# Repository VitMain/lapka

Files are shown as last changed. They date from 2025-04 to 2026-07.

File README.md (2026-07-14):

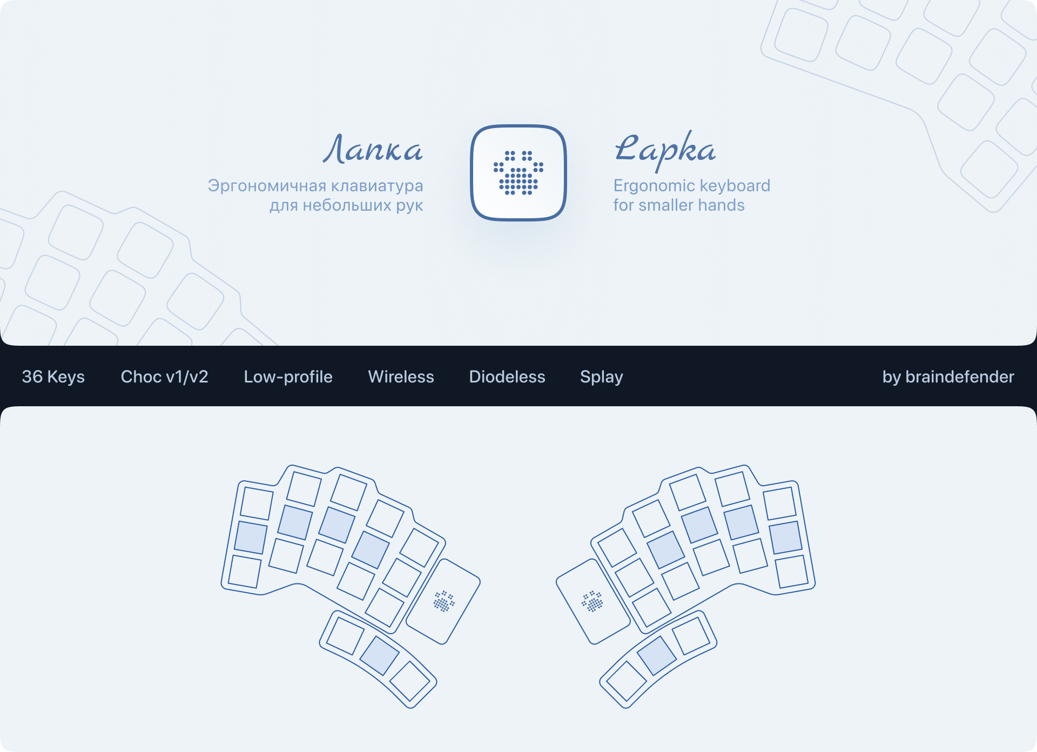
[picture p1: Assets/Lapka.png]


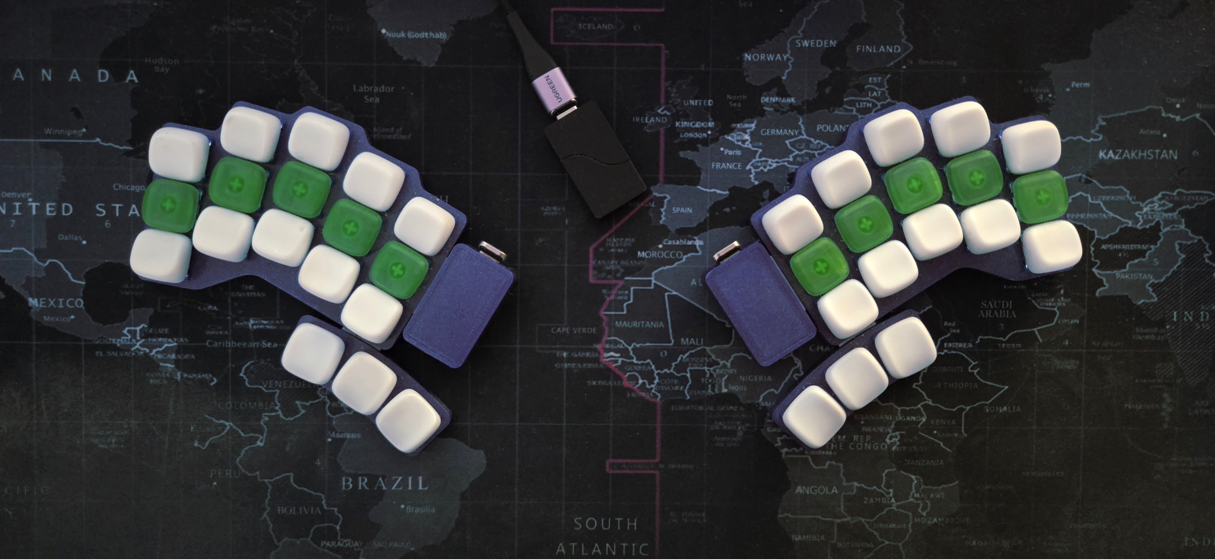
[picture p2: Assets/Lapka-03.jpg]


# Лапка

Беспроводная эргономичная сплит-клавиатура для тех, у кого лапки (:

**Особенности:**
- 36 клавиш, совместима с Choc v2 свитчами
- Direct-pin подключение — при сборке не требуются диоды
- Низкопрофильный корпус (свитчи практически касаются стола)

**Структура репозитория:**

| Директория | Описание |
| ---: | :--- |
| 3MF | Проект OrcaSlicer (для примера параметров печати) |
| Assets | Изображения и фото |
| Fusion | Проект Autodesk Fusion 360 |
| Gerbers | Gerber-файлы для производства плат |
| Guide | Описание [процесса сборки](./Guide/build-guide-ru.md) |
| KiCad | Проект KiCad (схема, плата, компоненты) |
| STL | 3D-модели частей корпуса |

Ссылки на актуальные прошивки:
- [ZMK](https://github.com/braindefender/lapka-zmk-config)
- [RMK](https://github.com/braindefender/lapka-rmk-config)

## RMK

Следуйте инструкциям в README.md репозитория с RMK прошивкой.

## ZMK

Используйте вариант подключения direct-pin, описанный в `lapka_wellum36_left.overlay` и `lapka_wellum36_right.overlay`.

Откройте GitHub Actions и найдите последний успешно собранный билд ветки `lapka-36`.
В нём будет артефакт сборки `firmware.zip`, который содержит все нужные для прошивки файлы.

Тестовая прошивка расположена в ветке `lapka-36-test`. В ней всего один слой и клавиши на тамб-кластере заменены на F1-F6. Это позволит увидеть нажатия клавиш на [key-test.ru](https://key-test.ru).

## История изменений

### v2.2
- Добавлена ссылка на репозиторий прошивки RMK

### v2.1
- Изменена ссылка на репозиторий прошивки ZMK

### v2
- Добавлена поддержка Choc v1
- Изменена разметка пинов
- Обновлена шелкография, логотип перенесён на Cu слой
- Добавлен проект Fusion 360

### v1
- Первый релиз. Только для Choc v2

# Lapka

Wireless ergonomic split keyboard for those who have paws (:

**Peculiarities:**
- 36 keys, Choc v2 compatible
- Direct-pin connection — no diodes needed required
- Low-profile case (switches almost touch the table)

**Repository structure:**

| Directory | Description |
| ---: | :--- |
| 3MF | OrcaSlicer project files (printing parameters example) |
| Assets | Images and photos |
| Fusion | Autodesk Fusion 360 project |
| Gerbers | Gerber-files for PCB production |
| Guide | [Build guide](./Guide/build-guide-en.md) |
| KiCad | KiCad project (schematics, PCB design, components) |
| STL | 3D-models of case parts |

Links to the current firmwares:
- [ZMK](https://github.com/braindefender/lapka-zmk-config).
- [RMK](https://github.com/braindefender/lapka-rmk-config).

## RMK

Follow the instructions in the README.md file of the RMK firmware repository.

## ZMK

Use direct pin layout, described in `lapka_wellum36_left.overlay` and `lapka_wellum36_right.overlay`.

Open GitHub Actions and find latest successful build of branch `lapka-36`.
In that build you'll find artifact `firmware.zip`, which contain all the neccessary firmware files.

Test firmware is located in branch `lapka-36-test`. There are single layer with F1-F6 keys on the thumb-cluster. That will help to see keypresses on the [key-test.ru](https://key-test.ru).

## Changelog

### v2.2
- Added link to RMK Firmware repo

### v2.1
- Changed link to ZMK Firmware repo

### v2
- Added support for Choc v1
- Changed pin layout
- Updated silk-screen, moved logo to Cu layer
- Added Fusion 360 project

### v1
- Initial release. Only for Choc v2

## Фото / Photos

### Original

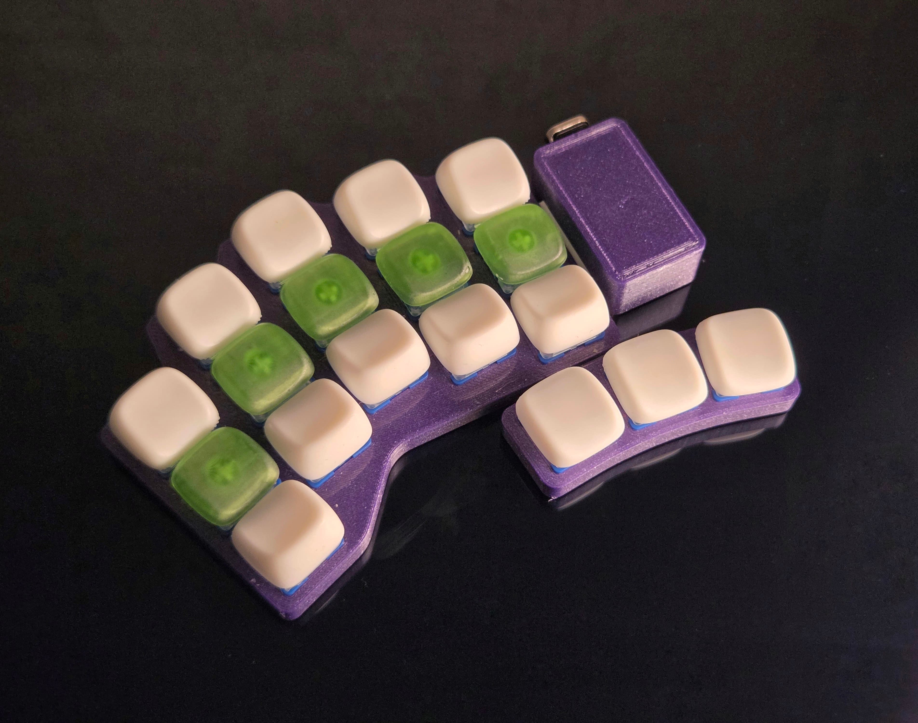
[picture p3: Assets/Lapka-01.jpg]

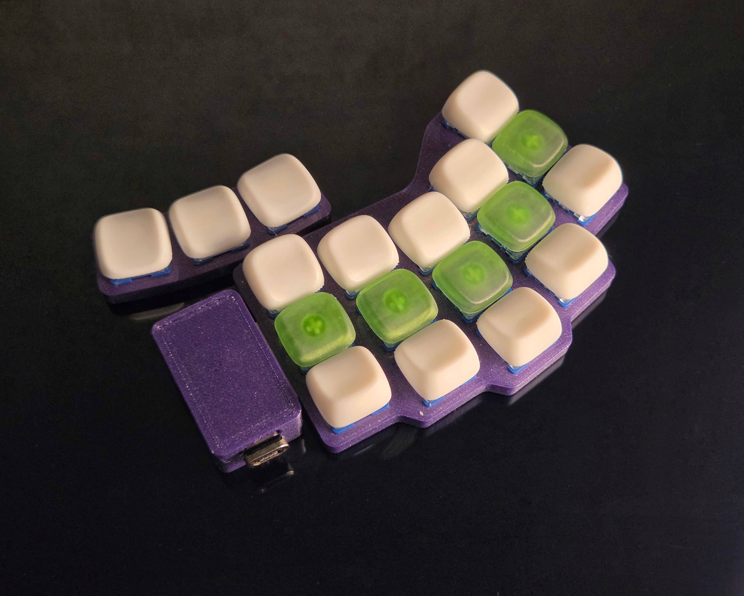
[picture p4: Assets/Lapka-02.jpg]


### From awesome people

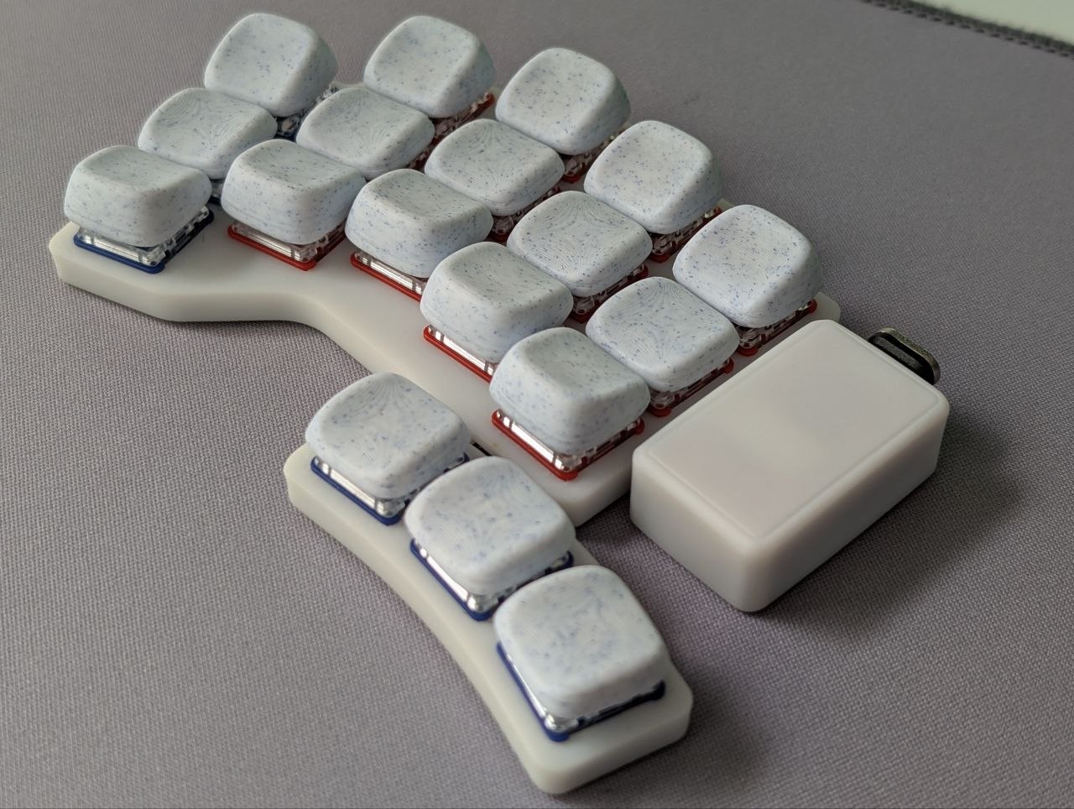
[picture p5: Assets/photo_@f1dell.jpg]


> by [Макс / f1dell](https://t.me/f1dell)

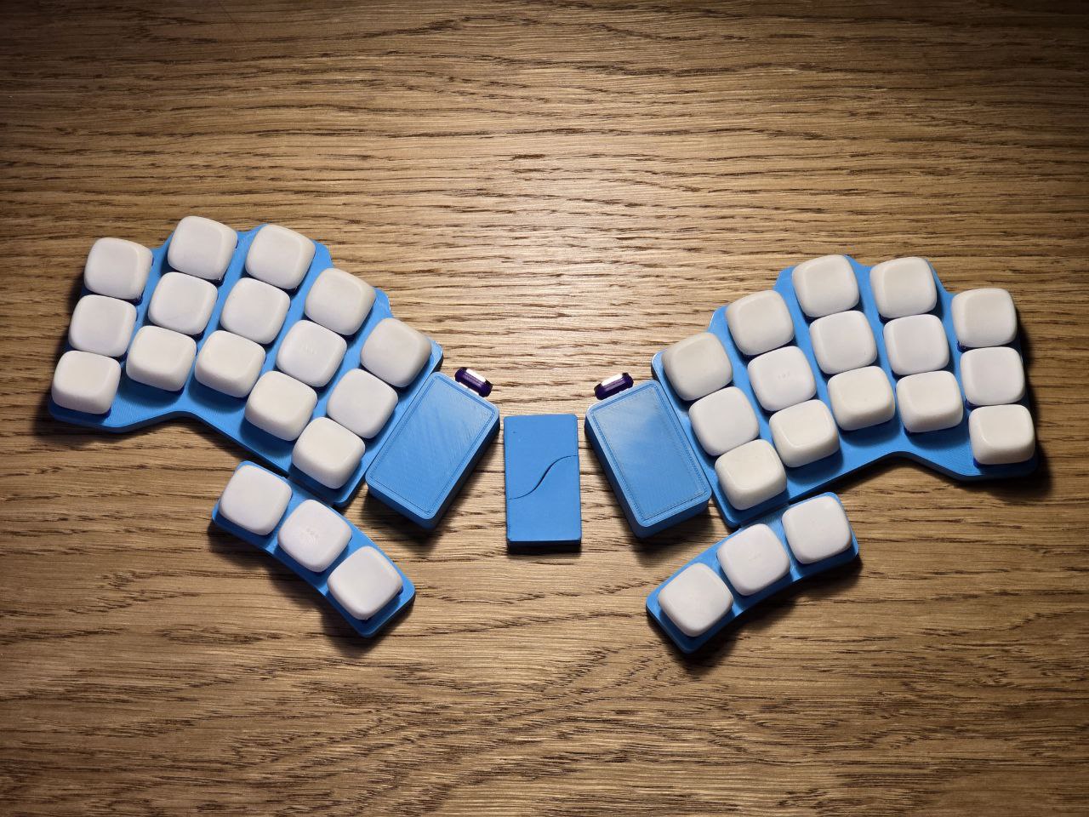
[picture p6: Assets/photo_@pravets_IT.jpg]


> by [Иосиф Правец](https://t.me/pravets_IT)

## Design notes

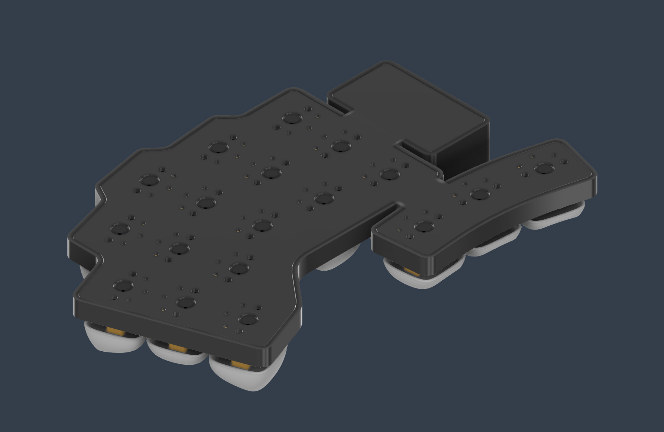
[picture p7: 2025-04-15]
Assets/Bot-View.jpg

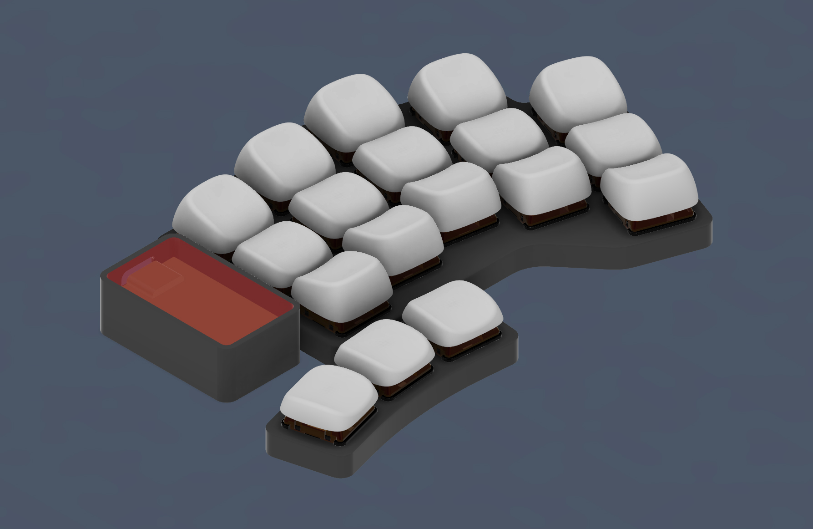
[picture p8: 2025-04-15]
Assets/Top-View.jpg

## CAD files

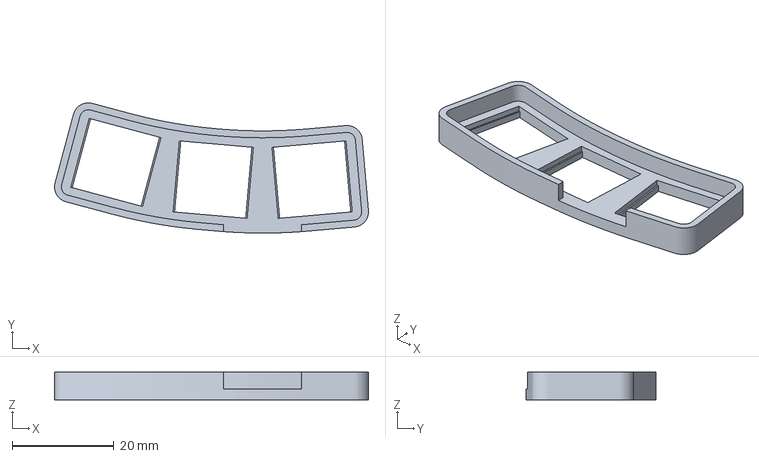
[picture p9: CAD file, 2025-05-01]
3MF/Lapka-Thumbs.3mf
61.7 x 25.6 x 5.50 mm

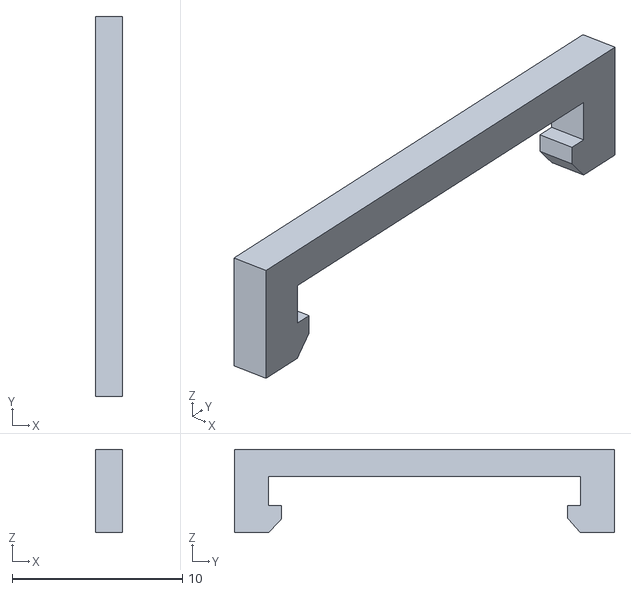
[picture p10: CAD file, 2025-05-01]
STL/Lapka_Spacer.stl
1.60 x 22.3 x 4.90

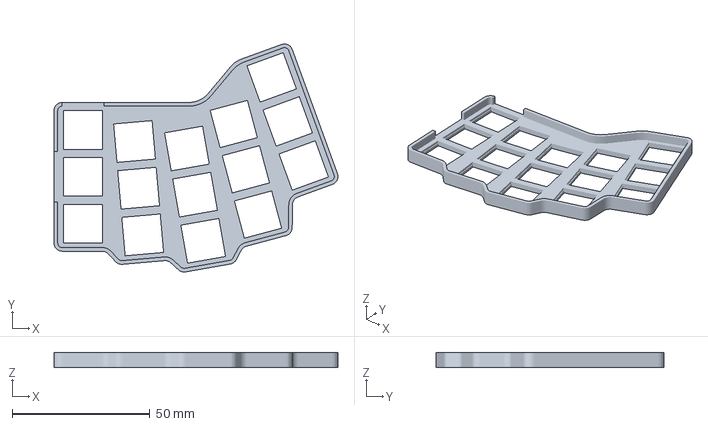
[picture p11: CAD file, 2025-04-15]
3MF/Lapka-Frame.3mf
103.0 x 82.7 x 5.50 mm

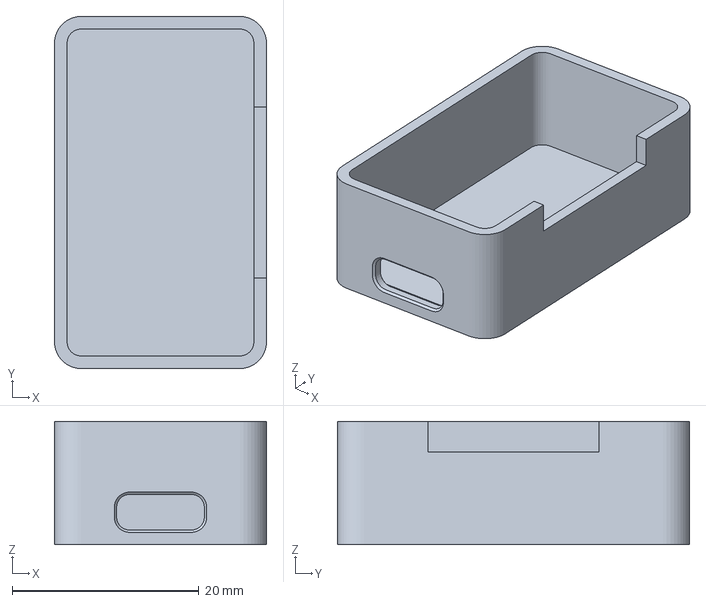
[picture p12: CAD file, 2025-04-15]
3MF/Lapka-Cover.3mf
22.7 x 37.7 x 13.2 mm

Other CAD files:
STL/Lapka_Cover.stl
STL/Lapka_Frame.stl
STL/Lapka_Thumbs.stl

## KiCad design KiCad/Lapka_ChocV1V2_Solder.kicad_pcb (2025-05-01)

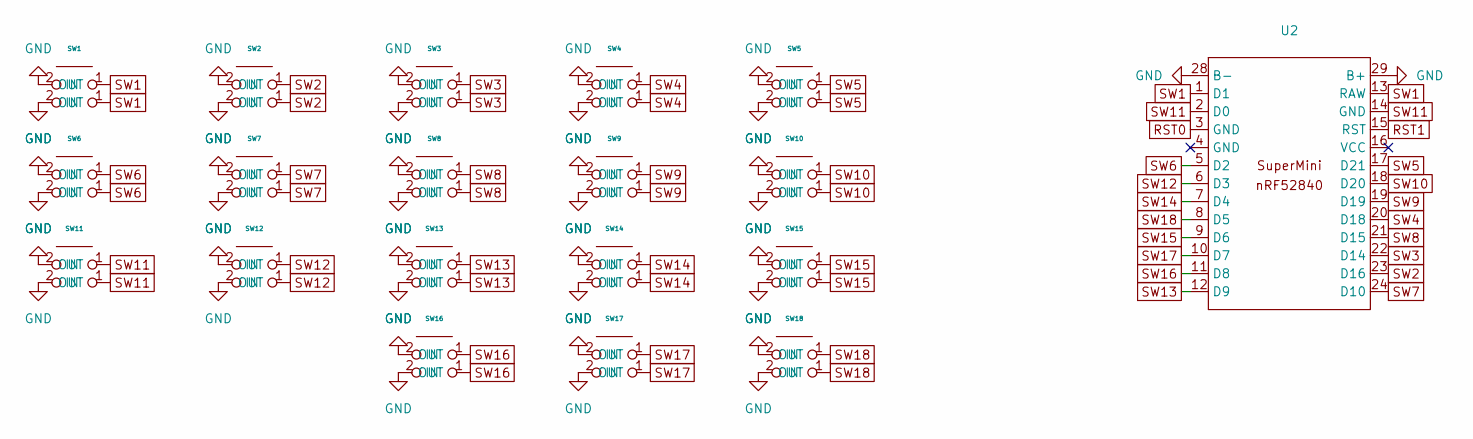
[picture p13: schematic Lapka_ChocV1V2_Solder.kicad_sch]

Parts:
SW1, SW2, SW3, SW4, SW5, SW6, SW7, SW8, SW9, SW10, SW11, SW12, SW13, SW14, SW15, SW16, SW17, SW18: SW_KLPv1v2_DS
U2: SuperMini NRF52840

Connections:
GND: SW1.2 (IN), SW2.2 (IN), SW3.2 (IN), SW4.2 (IN), SW5.2 (IN), SW6.2 (IN), SW7.2 (IN), SW8.2 (IN), SW9.2 (IN), SW10.2 (IN), SW11.2 (IN), SW12.2 (IN), SW13.2 (IN), SW14.2 (IN), SW15.2 (IN), SW16.2 (IN), SW17.2 (IN), SW18.2 (IN), U2.28 (B-), U2.29 (B+)
RST0: U2.3 (GND)
RST1: U2.15 (RST)
SW1: SW1.1 (OUT), U2.1 (D1), U2.13 (RAW)
SW2: SW2.1 (OUT), U2.23 (D16)
SW3: SW3.1 (OUT), U2.22 (D14)
SW4: SW4.1 (OUT), U2.20 (D18)
SW5: SW5.1 (OUT), U2.17 (D21)
SW6: SW6.1 (OUT), U2.5 (D2)
SW7: SW7.1 (OUT), U2.24 (D10)
SW8: SW8.1 (OUT), U2.21 (D15)
SW9: SW9.1 (OUT), U2.19 (D19)
SW10: SW10.1 (OUT), U2.18 (D20)
SW11: SW11.1 (OUT), U2.2 (D0), U2.14 (GND)
SW12: SW12.1 (OUT), U2.6 (D3)
SW13: SW13.1 (OUT), U2.12 (D9)
SW14: SW14.1 (OUT), U2.7 (D4)
SW15: SW15.1 (OUT), U2.9 (D6)
SW16: SW16.1 (OUT), U2.11 (D8)
SW17: SW17.1 (OUT), U2.10 (D7)
SW18: SW18.1 (OUT), U2.8 (D5)

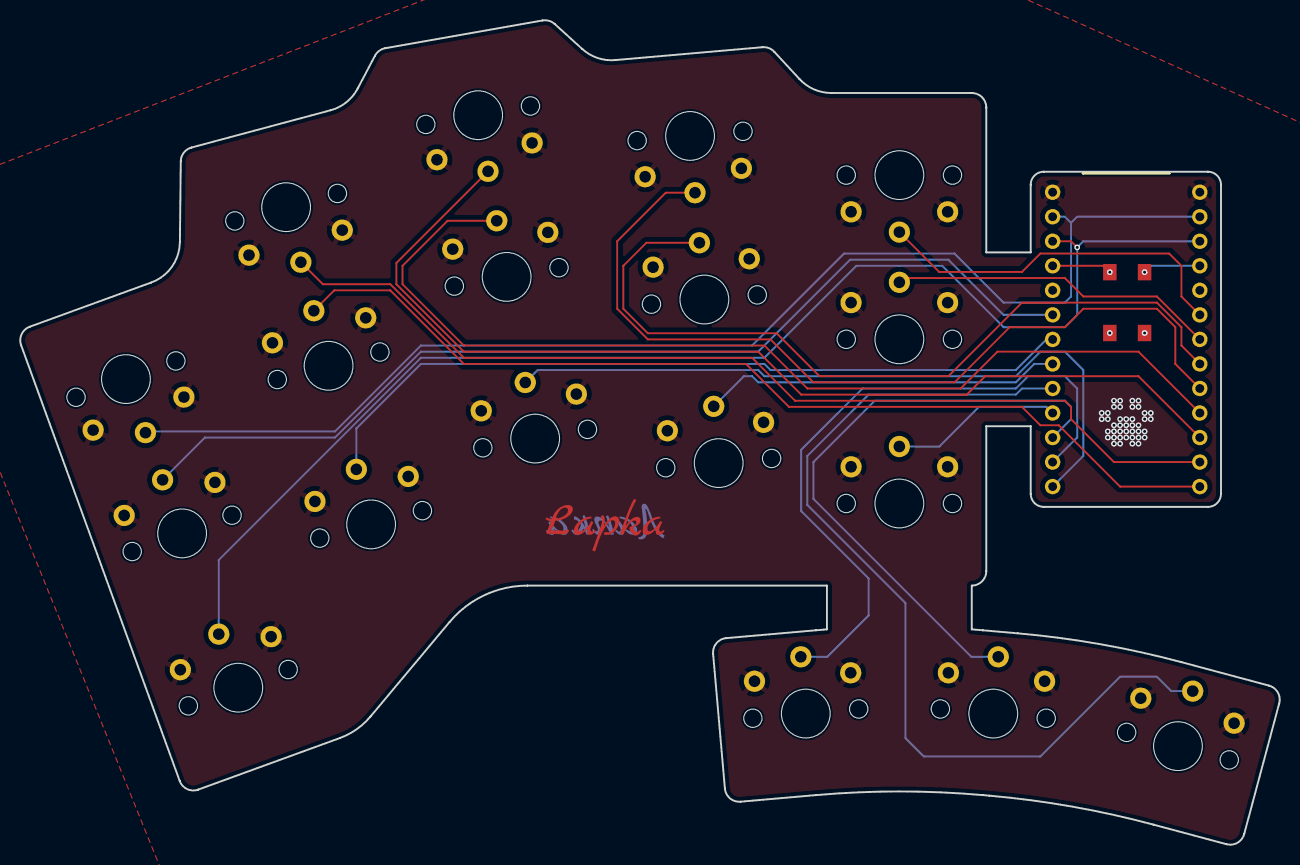
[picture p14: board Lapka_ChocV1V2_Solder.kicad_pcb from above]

Board: 2 copper layers, 130.4 x 85.4 mm, 19 parts (0 on the bottom side), 19 nets.

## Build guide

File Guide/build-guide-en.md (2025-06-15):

# Guide

To assemble the keyboard you will need the following parts:

### 1. The boards themselves, 2 pieces.

They can be ordered from any board manufacturer using Gerber files from the repository. I used the services of [SJ PCB](https://aliexpress.ru/store/129841), but you can use JLCPCB, PCBWay or anything else.

### 2. Controllers.

The board is compatible with nRF52840 or nice!nano. You will need 2 or 3 of them, depending on whether you want to use a Dongle, which will extend the life of a single charge several times. You can buy nRF52840 on [AliExpress](https://aliexpress.ru/item/1005008099333183.html).

> Warning! Sometimes controllers can come defective, so it's worth ordering more of them. They're inexpensive and certainly enough to save your nerves.

### 3. Batteries.

You will need 2 batteries of the `041230` format. I bought them on OZON, but you can also look for them on AliExpress or Amazon.

### 4. Switches.

You will need 36 switches of Choc v1 or Choc v2 format. MX or GLP switches are not suitable! Choose to your taste and color. I used [Kailh Deep Sea Islet](https://aliexpress.ru/item/1005004684367347.html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)

### 5. Keycaps.

If Choc v1 switches are used, then almost any keycaps for Choc switches will work.

If Choc v2 switches are used, then only custom keycaps that have Choc-spacing (18×17 vs 19×19 for MX) and at the same time an MX stem (compatible with Choc v2 switches) will work. For example, you can use [KLP Lame](https://github.com/braindefender/KLP-Lame-Keycaps).

### 6. Body parts
Which consist of:
1. `Frame` — the main part for the typing cluster.
2. `Thumb` — part for the thumb cluster.
3. `Cover` — part that covers the controller.
4. (Optional) `Spacer` — a small bracket that is installed between the Frame and Cover. It is needed if the Cover part was printed with a small shrinkage and it dangles on the board.

> The repository contains both STL files and 3MF files with examples of my print settings.

### 7. (Optional) 2 buttons of the [SMD 4x4x1.5mm](https://aliexpress.ru/item/32802382507.html) format.

They are soldered to the bottom of the boards and serve for quick access to the Reset function.

<hr>

Having all the necessary parts, as well as a soldering iron, solder/paste and other little things for soldering, you can start the assembling process:

### 1. First, you need to make sure that the controllers work.

> This must be done **BEFORE** starting everything else!

To do this, you need to flash them with Debug firmware and make sure that all the pins press the corresponding keys. Check the functionality of the matrix using [key-test.ru](https://key-test.ru), clamping the contacts of the switches with tweezers.

### 2. Prepare the pin headers

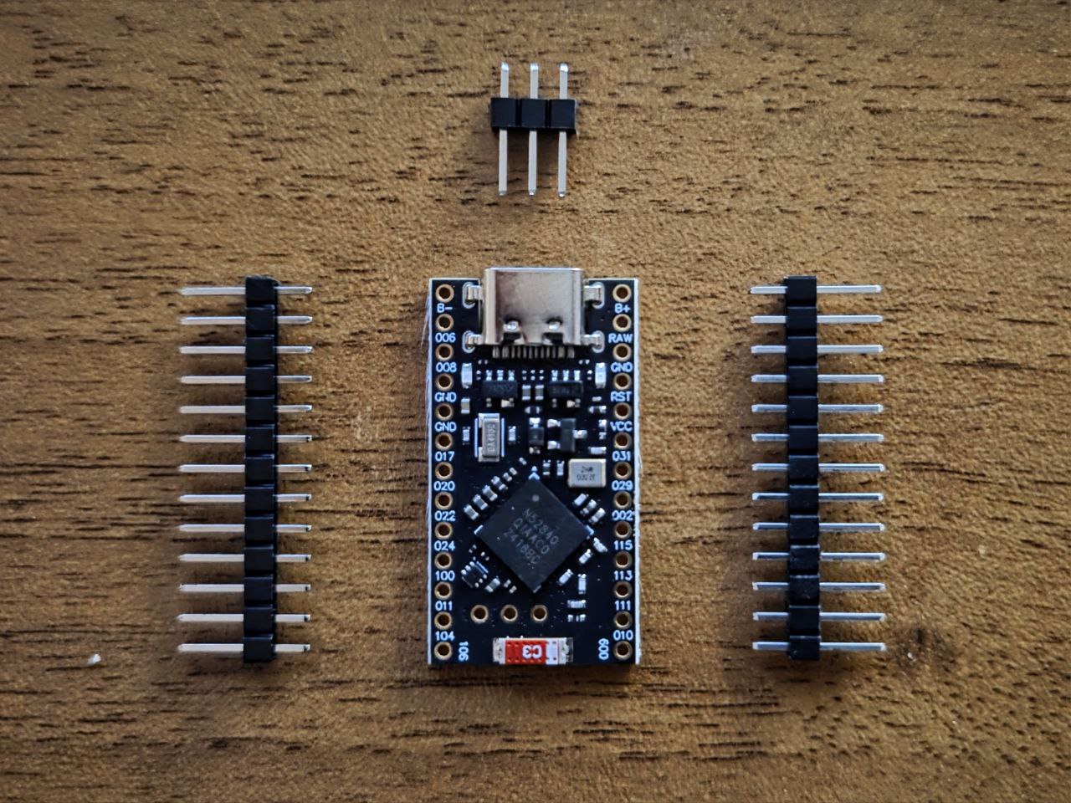
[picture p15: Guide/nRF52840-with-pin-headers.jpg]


There are three pin headers that come with controller: two long and one short. We'll need only two long ones.

Using the [pin layout](./pin_layout_v2.png), you need to remove the metal pins marked in red from the header. Red pins **DO NOT** need to be soldered.

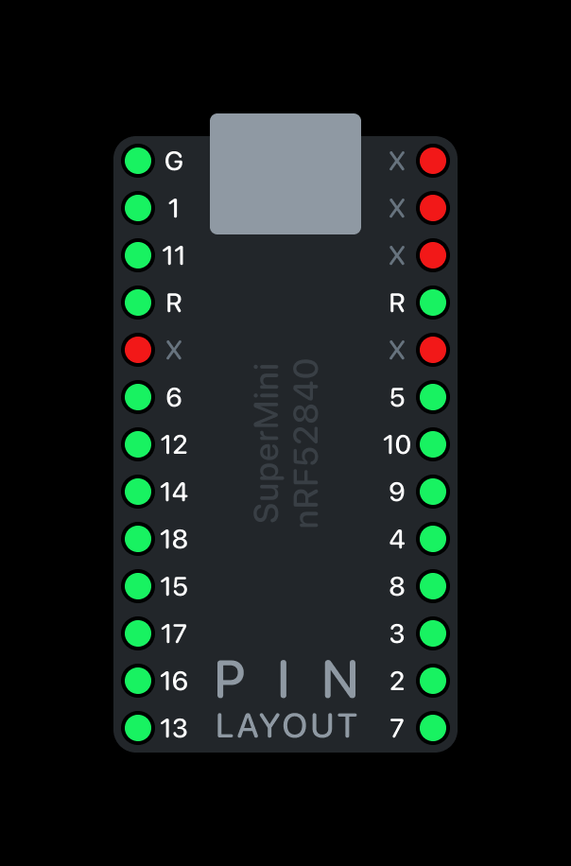
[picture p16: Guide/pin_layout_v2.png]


In order to accurately determine the height of the header's pins, you can remove the black plastic spacers from the short pin header and put them on the corners of the long pin headers. Having determined the desired height, you can cut off the excess with nippers.

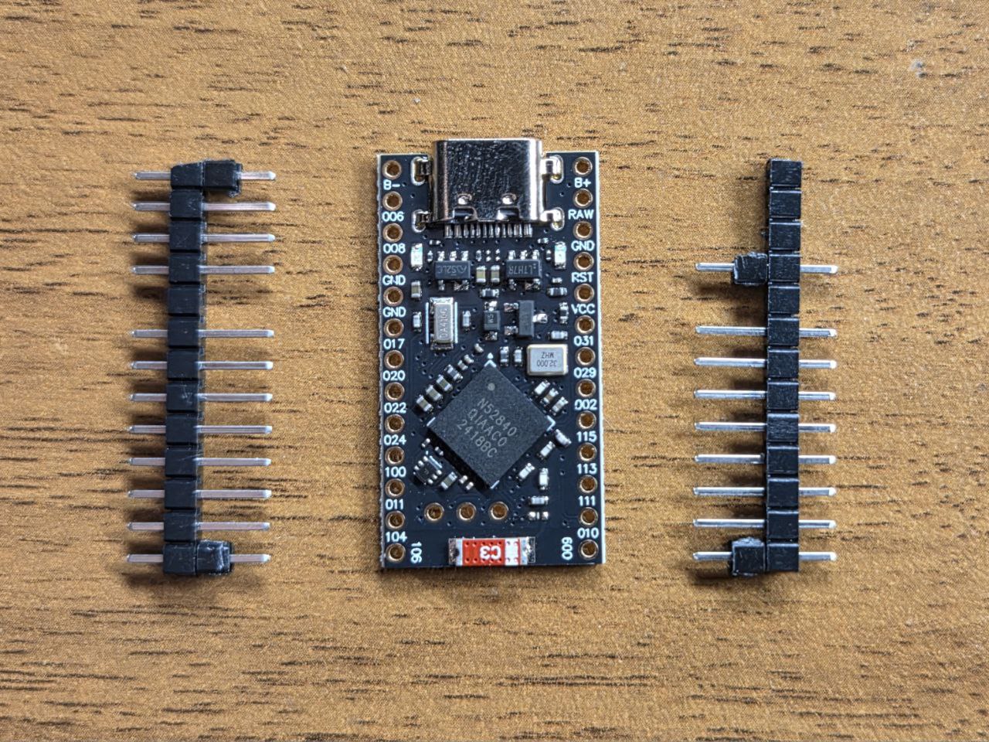
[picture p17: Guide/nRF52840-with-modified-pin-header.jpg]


### 3. Solder the headers.

Apply solder paste to the header pins on the board side, align the controller so that the headers are perpendicular to the board, and solder the headers to the board one by one.

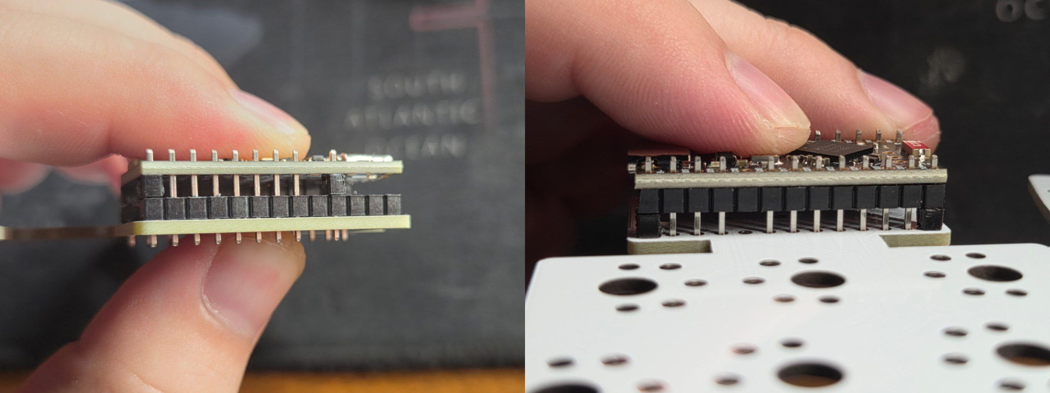
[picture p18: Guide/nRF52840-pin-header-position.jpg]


You'll get something like that:

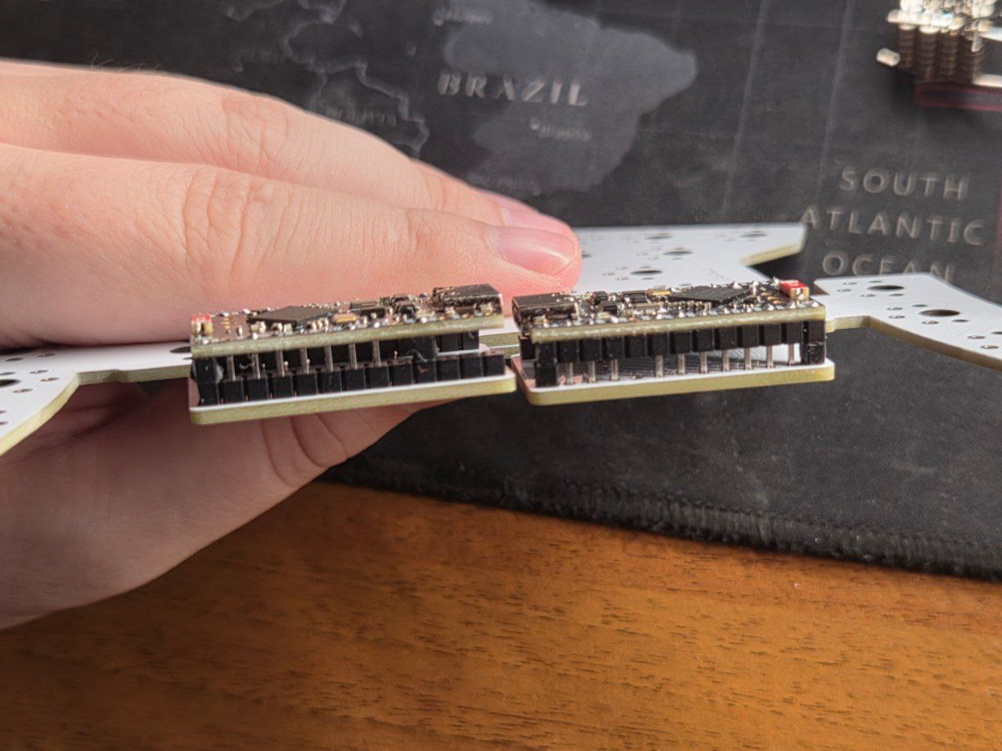
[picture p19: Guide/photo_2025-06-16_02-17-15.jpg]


> Attention! Both controllers should be facing up. The boards are symmetrical, so the headers should NOT be flipped or mirrored! They should be soldered in the same orientation as on the other half of the keyboard.

### 4. Install the body part

Put Frame and Thumb case parts and insert switches into them.

> Attention! The case parts should be located **between** the board and the switches.

### 5. Final soldering

Apply soldering paste to the contacts of the switches and solder them. Stick the battery between controller and PCB, then solder the battery wires to the pins `B+` and `B-` respectively. At this point, the controller will blink red or blue diodes. At about the same time, you can solder the Reset buttons, if you have them.

### 6. (Optional) Attach a Spacer piece between the Frame and Cover.

### 7. Flash the firmware

Connect the keyboard to the PC, go to the firmware mode in one of the ways:
- press Reset button twice
- short the button pins that is located on the back of the PCB twice
- short the `GND` and `RST` pins twice with tweezers

After this, the controller should connect to the PC as a USB drive.
Copy the firmware file to it and repeat for the other half.

### 8. Finale

Put the controller cover on. Stick the silicone bumpers via perimeter and... Done!
Do the same with the other half.

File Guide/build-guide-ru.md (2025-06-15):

# Инструкция

Для сборки клавиатуры тебе понадобятся следующие детали:

### 1. Непосредственно платы в количестве 2-х штук.

Их можно заказать у любого производителя плат, используя Gerber-файлы из репозитория. Я пользовался услугами [SJ PCB](https://aliexpress.ru/store/129841).

> Почти* актуальный список производителей плат можно посмотреть [здесь](https://t.me/devAlphaSierra/359).

### 2. Контроллеры.

Плата совместима с nRF52840 или nice!nano. Их понадобится 2 или 3 штуки, в зависимости от того, хочешь ли ты использовать Dongle, который продлит жизнь от одного заряда в несколько раз. Купить nRF52840 можно на [AliExpress](https://aliexpress.ru/item/1005008099333183.html).

> Внимание! Иногда контроллеры могут прийти бракованными, поэтому стоит заказать их побольше. Стоят они недорого и уж точно достаточно, чтобы сохранить твои нервы.

### 3. Аккумуляторы.

Понадобится 2 батареи формата `041230`. Я покупал на OZON, но ищется также и на AliExpress.

### 4. Свитчи.

Тебе понадобится 36 свитчей формата Choc v1 или Choc v2. MX или GLP свитчи не подходят! Выбирай на свой вкус и цвет. Я использовал [Kailh Deep Sea Islet](https://aliexpress.ru/item/1005004684367347.html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)

### 5. Кейкапы.

Если используются Choc v1 свитчи, то подойдут почти любые кейкапы для Choc свитчей.

Если используются Choc v2 свитчи, то подойдут только кастомные кейкапы, которые имеют Choc-spacing (18×17 против 19×19 у MX) и одновременно MX стем (совместимый с Choc v2 свитчами). Можно, например, использовать [KLP Lame](https://github.com/braindefender/KLP-Lame-Keycaps).

### 6. Детали корпуса

Который состоит из:

1. `Frame` — основная часть typing-кластера.
2. `Thumb` — часть для thumb-кластера.
3. `Cover` — часть, закрывающая контроллер.
4. (Опционально) `Spacer` — маленькая скоба, которая устанавливается между Frame и Cover. Она нужна, если Cover часть напечаталась с маленькой усадкой и он болтается на плате.

> В репозитории имеются как STL файлы, так и 3MF файлы с примерами моих настроек печати.

### 7. (Опционально) 2 кнопки формата [SMD 4x4x1.5mm](https://aliexpress.ru/item/32802382507.html).

Они припаиваются на нижнюю часть плат и служат для быстрого доступа к функции Reset.

<hr>

Имея все необходимые детали, а также паяльник, припой/пасту и прочие мелочи для пайки, можно приступать к сборке:

### 1. Нужно убедиться в том, что контроллеры работают правильно.

> Это нужно делать **ДО** начала всех других работ!

Для этого нужно прошить их Debug-прошивкой и убедиться в том, что все пины нажимают соответствующие клавиши. Проверить работоспособность матрицы с помощью [key-test.ru](https://key-test.ru), зажимая контакты свитчей пинцетом.

### 2. Подготавливаем гребёнку.



В комплекте с контроллерами есть три гребёнки: две длинных и одна короткая. Нам понадобятся только две длинных.

Ориентируясь на [разметку пинов](./pin_layout_v2.png) нужно удалить из длинных гребёнок металлические штырьки, помеченные на изображении красным цветом. Их припаивать **НЕ** нужно.



Для того, чтобы точно определить высоту гребёнки, можно снять чёрные пластиковые проставки с лишних пинов коротких гребёнок и насадить их по углам длинных гребёнок. Определив нужную высоту, можно откусить лишнее с помощью кусачек.



### 3. Припаиваем гребёнку.

Наносим паяльную пасту на пины гребёнки со стороны платы, выравниваем контроллер, так, чтобы гребёнки были перпендикулярны плате, и по-очереди припаиваем их к плате.



В итоге должно получиться что-то такое:



> Внимание! Оба контроллера должны быть ориентированы вверх. Платы симметричны, поэтому пины гребёнки НЕ нужно переворачивать или отзеркаливать! Они должны быть припаяны в той же ориентации, что и на другой половинке клавиатуры.

### 4. Устанавливаем корпус.

Надеваем на плату Frame и Thumb части корпуса. Вставляем в них свитчи.

> Внимание! Части корпуса должны находиться **между** платой и свитчами.

### 5. Финальная пайка.

Наносим паяльную пасту на контакты свитчей и припаиваем сами свитчи. Просовываем аккумулятор между платой и контроллером, а затем припаиваем его провода к пинам `B+` и `B-` соответственно. В этот момент контроллер замигает красным и/или синим диодами. Примерно в это же время, можно припаять кнопки Reset, если они у вас есть.

### 6. (Опционально) Закрепить проставочную деталь между деталями Frame и Cover

### 7. Прошивка.

Подключаем клавиатуру к ПК, переходим в режим прошивки одним из способов:
- дважды нажав на кнопку Reset
- дважды замкнув горизонтальные пины на обратной стороне платы (где должна быть кнопка Reset).
- дважды замкнув пины `GND` и `RST`, например, с помощью пинцета.

После этого контроллер должен подключиться к ПК как USB-накопитель.
Копируем файл с прошивкой в него и повторяем для другой половинки.

### 8. Финал.

Надеваем крышку контроллера. Приклеиваем силиконовые ножки по периметру, и... Готово!
Повторяем всё то же самое с другой половинкой.

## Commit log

2025-04-15 feat: initial release
    [Lapka-Cover.3mf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]
2025-04-15 feat: add direct pin notice
2025-05-01 major: add choc-v1 support
    [Lapka-B_Cu.gbl, Lapka-B_Mask.gbs, Lapka-B_Paste.gbp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]
2025-05-01 fix: move logos to Cu layers
    [Lapka_ChocV1V2_Solder-B_Cu.gbl, Lapka_ChocV1V2_Solder-B_Mask.gbs, Lapka_ChocV1V2_Solder-B_Paste.gbp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]
